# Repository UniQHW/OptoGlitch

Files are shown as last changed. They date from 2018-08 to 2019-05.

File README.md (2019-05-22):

# OptoGlitch

GIF

Turning an Arduino, a LED and a Photo Resistor into an physical glitch art filter!

## Showcase

Original:
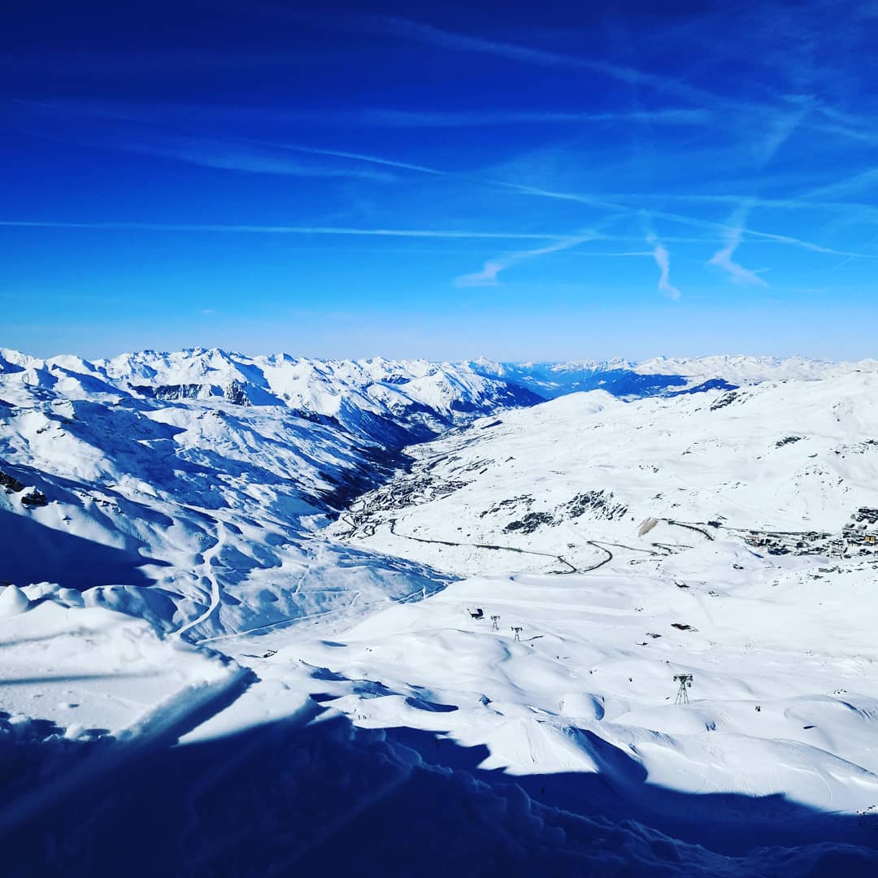
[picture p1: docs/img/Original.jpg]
Original


Parsed:
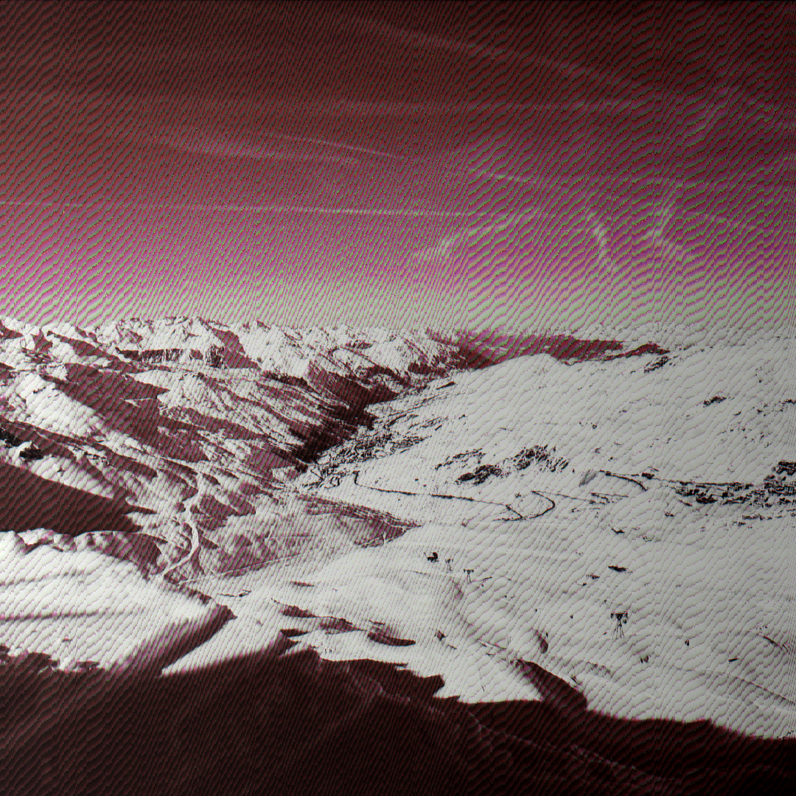
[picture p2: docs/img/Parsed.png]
Parsed


## Prelude

It is absolutely no secret that I have an unhealthy obsession with the aesthetics manifested by analogous errors. Despite the fact that the VHS Cassette was already being replaced by its digital competitor, the DVD, by the time I was born, I was still fortunate enough to become one of the last witnesses of the legendary video format. The time stamps, the "play" button, the washed out colors and static noise will always invoke a warm feeling of nostalgia for me. And it is due to this induced nostalgia, that my desire in glitch art strives after the analogous error.

Since the introduction of digital media formats, we have become spoiled in media quality. As an result, we now treat analogous error as an visual aesthetic, and ironically often attempt to digitally recreate it. I myself must obviously admit, that I proudly contribute to the digital recreation of analogous error, in form of glitch art. While I have yet to get my hands on a proper VHS recorder or camcorder, I have attempted to improvise by finding alternate ways of analogous data transfer that do not require access to the rather complex electronics found in a VHS recorder. And that is exactly what has lead to this project. While the results certainly vary from VHS glitches, I must admit that I am still very satisfied by the errors caused through analogous noise.

## Overview

OptoGlitch is an Arduino project that attempts to artificially induce analogous errors by passing image data through an optocoupler circuit.

### Hardware
The optocoupler consists of nothing more than a photo resistor, a LED (blue in our case) and two resistors, where one drives the LED (220 Ohm) and the other acts as a voltage reference for the photo resistor input (330 Ohm).

The schematic looks as it follows:

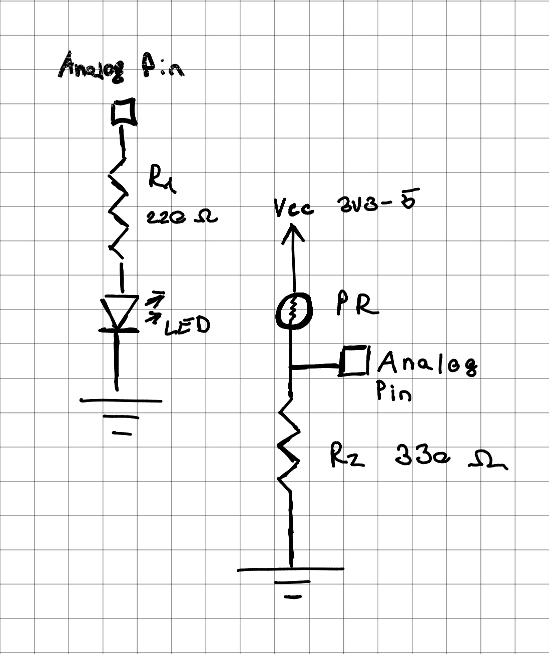
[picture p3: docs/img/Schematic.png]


Since the choice of analog pins is interchangeable, the schematic generalizes them. In the case of this project, the currently utilized pins can be found in the [pin header](src/Pins.h).

Since I was so satisfied with the results delivered by this project, I have also decided to 3D print an enclosure for the circuitry. The internal wiring estimates the following sketch:

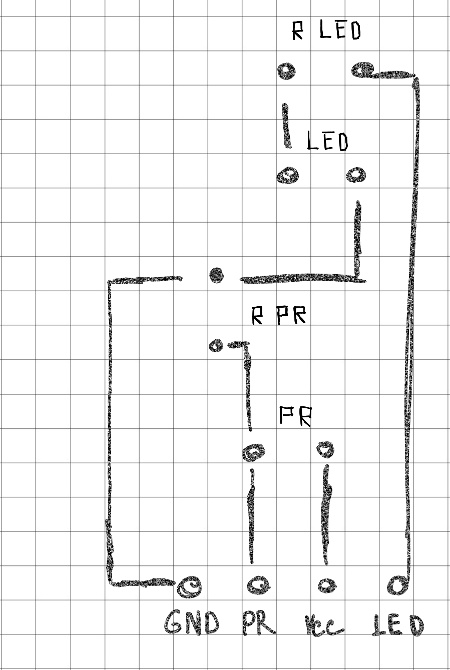
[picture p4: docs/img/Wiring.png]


In its enclosure, the device turned out to look and function quite neatly:

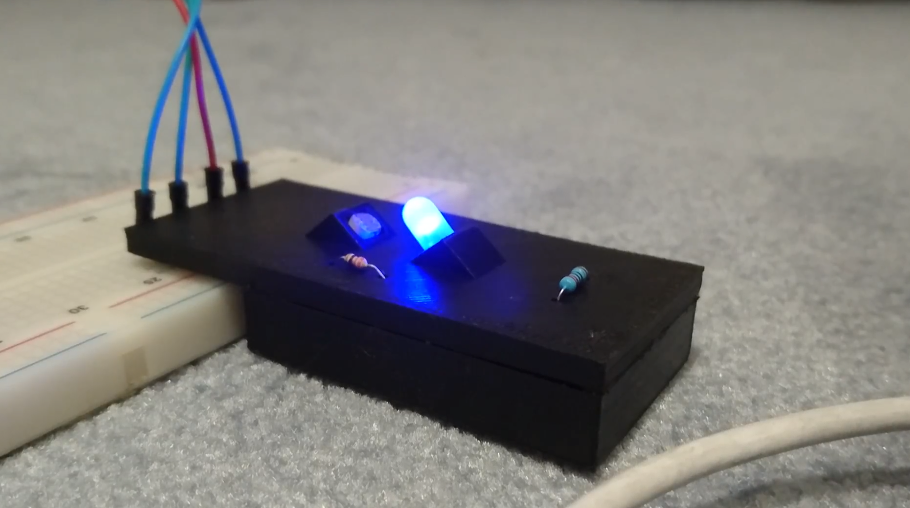
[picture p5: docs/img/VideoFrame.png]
3D Printed Enclosure


Notice that the photo resistor and LED are raised at a 45 degree angle. This grants easier access for manual interference and allows the photo resistor to capture environmental noise.

The STL files for the 3D printed enclosure can be found here:

- [top](stl/Top.stl)
- [bottom](stl/Bottom.stl)

### Software

The transmission of data is achieved by setting the LED to the brightness of the pixel value (ex. (255, 0, 120) would first set the LED to 255 brightness then 0 brightness and then 120 brightness). The photo resistor captures the brightness of the LED, and the software attempts match the photo resistor input to its original pixel value through various calibration methods. Since the process is analogous, it is prone to noise caused by external light sources. Additionally, the Arduino can only distinguish between a finite set of voltage levels. These, and many more factors result in erroneous readings, which are then responsible for the glitch aesthetics.

#### Calibration
Since the photo resistor readings are ranged in values 0 - 1023 (unlike the LEDs range of 0 - 255) and will substantially vary from the LED brightness, they must be calibrated for images not to become completely unrecognizable. The Arduino software offers a total of two calibration modes, each compensating for the value deviation in a different way.

##### Standard Deviation

With this calibration method, all 256 LED brightness levels (0 - 255) are compared to the photo resistor input prior image parsing. From the received set of mean readings (256 values in total), the Arduino then computes the standard deviation between the mean readings and the LED brightness that they should match.

Once the image parsing process begins, all photo resistor values are subtracted by- or added to the standard deviation, depending whether the photo resistor value is smaller or greater than the LED brightness.

To set the calibration mode to standard deviation, pass the following serial command while the device is idling:

```
set cmode stddev
```

##### Lookup Table

Just as with the standard deviation, the lookup table calibibration takes place before an image is parsed. The lookup table calibration loads a total of 256 photo resistor readings, one for each LED brightness, into an array.

Once the image parsing process begins, the photo resistor value is mapped to its nearest matching array entry.

**The lookup table calibration is the default calibration mode** and is vastly superior to the standard deviation when it comes to color accuracy. Its slight drawback comes from the prolonged parsing time.

To set the calibration mode to lookup table, pass the following serial command while the device is idling:

```
set cmode lookup
```

##### No calibration

If one desires to utilize photo resistor readings in their pure form, calibration can be disabled with the following serial command:

```
set cmode none
```

In most cases this will yield very light images since the photo resistor readings can range from values 0 - 1023, thus any readings that are greater than 255 will be reduced to a value of 255.

##### Other properties

The intensity of error can be further reduced through the implementation of a mean reading. A mean reading is determined by calculating the average of a set of photo resistor inputs for a specific brightness, rather than just relying on a single sample. The amount of samples to calculate the mean can be specified through the serial console via the `set samples` command. For instance, `set samples 0` will skip the calculation of a mean and simply rely on a single reading. Contrary, `set samples 100` will tell the Arduino to collect a total of 100 samples per brightness and then calculate the mean. By default, the `samples` property is set to 0.

Original:

Original

---

`set samples 0` on standard deviation:

No Args

Parse time: 00:30 Seconds

---

`set samples 50` on standard deviation:

50 Samples

Parse time: 03:26 min

---

`set samples 100` on standard deviation:

100 samples

Parse time: 06:03 min

With sample rate, color accuracy and parse time rises.

Further, we tend to reach the end of an threshold, as change in the mean reduces with more values provided.

Another property that can greatly reduce error is the `transition` property. Just like the mean sample rate, the transition property can be set through the serial console via the `set transition` command. The transition property defines the given time in ms for the LED to change its brightness. Giving the LED more time to change its brightness reduces the risk of developing artifacts from the previous pixel value. By default the transition time is set to 0, as such an error often provides desired aesthetics.

Original:

Original

---

`set transition 0` on standard deviation:

No Args

Parse time: 00:30 Seconds

---

`set transition 1`  on standard deviation:

1 ms transition

Parse time: 01:00 min

---

`set transition 5` on standard deviation:

5 ms transition

Parse time: 03:00 min

---

`set transition 10` on standard deviation:

10 ms transition

Parse time: 05:31 min

Once again, the accuracy and time rises. Obviously an LED only a fixed amount of time to fully change its brightness. As a result, it is isn't recommended to set this property to values above 10ms, as no notable improvements should be visible.

Utilizing both properties will clearly yield the best results, if those are desired:

Original:

Original

---

`set samples 100` and `set transition 5` on standard deviation:

Samples and Transition

Parse time: 08:34 min

### Usage

Since this project revolves primarily around the distortion of image files, I have written a host sided tool in python called [ParseImage.py](host/ParseImage.py), which reads an image file and parses each pixel by pixel through the OptoGlitch via serial communication.

The following python libraries are required by [ParseImage.py](host/ParseImage.py):

- [pySerial](https://pyserial.readthedocs.io/en/latest/index.html)
- [Pillow](https://pillow.readthedocs.io/en/latest/)

Usage:
```
usage: ParseImage.py [-h] [-p PORT] [-b BAUD] [-c CALIBRATION] [-dt TIMEOUT]
                     [-ht HOST_TIMEOUT] [-t TRANSITION] [-s SAMPLES]
                     [-nmax NOISE_MAX] [-nmin NOISE_MIN]
                     img

Parses images through the Arduino optocoupler

positional arguments:
  img                   Path to an image file

optional arguments:
  -h, --help            show this help message and exit
  -p PORT, --port PORT  Serial port (Default '/dev/ttyACM0')
  -b BAUD, --baud BAUD  Baud rate (Default 115200)
  -c CALIBRATION, --calibration CALIBRATION
                        Calibration mode (none, stddev, lookup)
  -dt TIMEOUT, --timeout TIMEOUT
                        Device serial communication timeout (Default 0, no
                        timeout)
  -ht HOST_TIMEOUT, --host_timeout HOST_TIMEOUT
                        Host serial communication timeout (Default 0, no
                        timeout)
  -t TRANSITION, --transition TRANSITION
                        Transition time for LED (Default 0, no transition
                        time)
  -s SAMPLES, --samples SAMPLES
                        PR input samples to determine a mean reading (Default
                        0, rely on a single sample only)
  -nmax NOISE_MAX, --noise_max NOISE_MAX
                        Maximum digitally generated noise
  -nmin NOISE_MIN, --noise_min NOISE_MIN
                        Minimum digitally generated noise
```

#### Example

In the following example we parse an image with the calibration mode set to the **standard deviation**, the transmission time set to **1 ms** and the mean sample rate set at **50 samples**:

```
python ParseImage.py -c stddev -t 1 -s 50 image.png
```

## Further reading

If you are interested as to why the OptoGlitch produces some of its unique glitch artificats, then I encourage you to take a look at [this document](https://docs.google.com/document/d/1IXgLr-epezUETSYK8bRIUSsdWn0loQHT_kls9pORURU/edit?usp=sharing), where I go as far as to inspect the device with an oscilloscope.

## License

This project is licensed by the GPLv3

```
Copyright (C) 2018 Patrick Pedersen <ctx.xda@gmail.com>

This program is free software: you can redistribute it and/or modify
it under the terms of the GNU General Public License as published by
the Free Software Foundation, either version 3 of the License, or
(at your option) any later version.

This program is distributed in the hope that it will be useful,
but WITHOUT ANY WARRANTY; without even the implied warranty of
MERCHANTABILITY or FITNESS FOR A PARTICULAR PURPOSE.  See the
GNU General Public License for more details.

You should have received a copy of the GNU General Public License
along with this program.  If not, see <https://www.gnu.org/licenses/>.
```

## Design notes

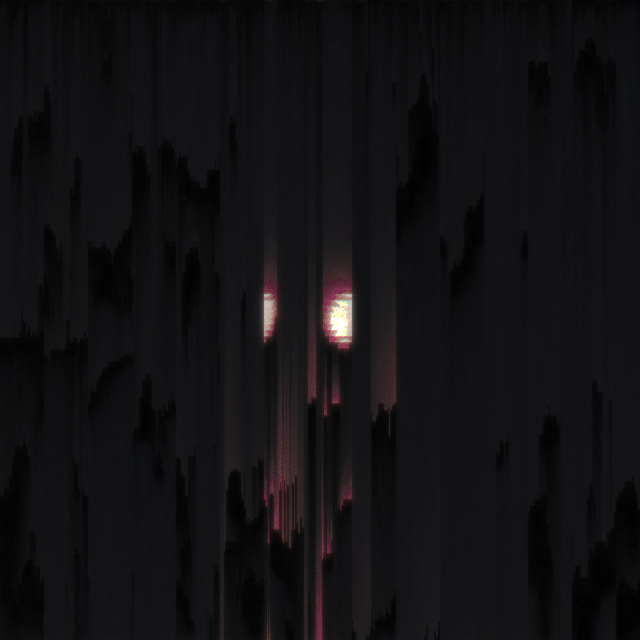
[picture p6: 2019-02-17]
host/Parsed.png

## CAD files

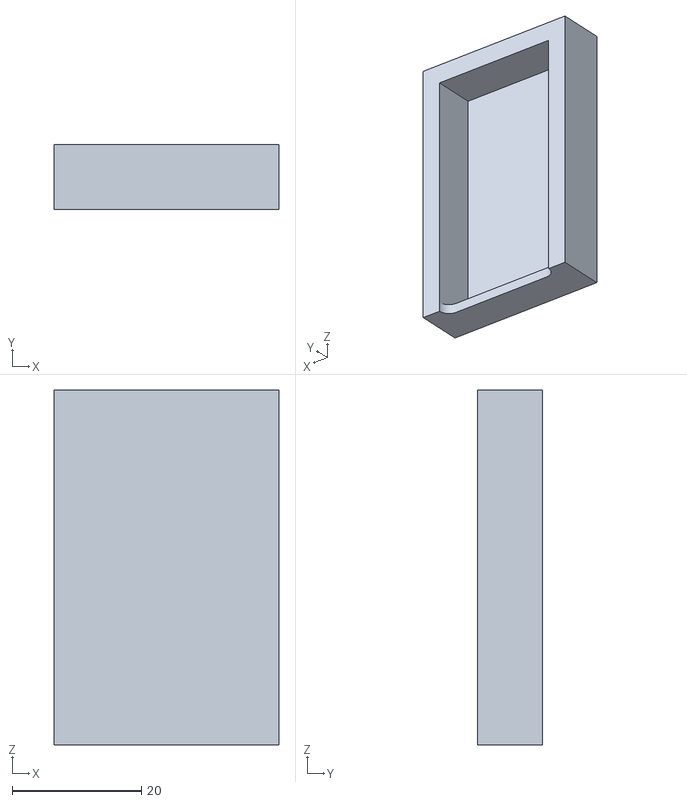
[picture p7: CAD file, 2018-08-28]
stl/Bottom.stl
34.8 x 10.0 x 55.0

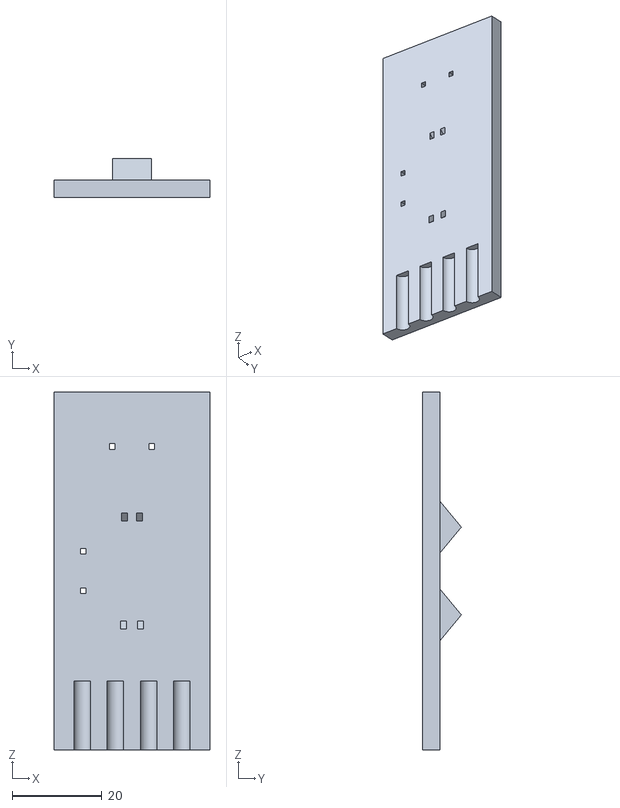
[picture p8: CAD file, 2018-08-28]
stl/Top.stl
34.8 x 8.66 x 80.0

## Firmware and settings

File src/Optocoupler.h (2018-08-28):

/*

* Copyright (C) 2018 Patrick Pedersen <ctx.xda@gmail.com>

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
 * Description:
 * Provides the main optocoupler class.

*/

#include <Arduino.h>

#pragma once

#define APPEND_SPACE(STR)             STR " "

// Set Arguments
#define SET_ARG_CALIBRATION_MODE      "cmode"                          // Set calibration mode
#define SET_ARG_TIMEOUT               "timeout"                        // Set communication timeout
#define SET_ARG_TRANSITION_TIME       "transition"                     // Set LED transition time
#define SET_ARG_MEAN_SAMPLES          "samples"                        // Set size of PR sample pool to determine a mean value
#define SET_ARG_NOISE_GENERATOR_MAX   "nmax"                           // Maximum random noise that can be generated
#define SET_ARG_NOISE_GENERATOR_MIN   "nmin"                           // Minimum random noise that must be generated
#define MIN_SET_ARG_SIZE              sizeof(SET_ARG_NOISE_GENERATOR_MAX) // Option with least characters

// Calibartion mode arguments
#define CALIBARTION_MODE_ARG_NONE     "none"   // No calibration
#define CALIBARTION_MODE_ARG_STDDEV   "stddev" // Standard deviation
#define CALIBARTION_MODE_ARG_LOOKUP   "lookup" // Lookup table

// LOOKUP TABLE SIZE
#define LOOKUP_TABLE_SIZE         1024 // Max possble analog read values

// Default properties
#define DEFAULT_TIMEOUT           0
#define DEFAULT_TRANSMISSION_TIME 0
#define DEFAULT_MEAN_SAMPLES      0
#define DEFAULT_CALIBRATION_MODE  lookup

// Typedefs
typedef unsigned long payload_size_t;

// Calibration Modes
enum CalibrationMode
{
  none,    // NO CALIBRATION (Colors will be very inacurate)
  stddev,  // Standard deviation
  lookup   // Mean Lookup table
};

// Optocoupler
// -----------------------------------------
// A pseudo-random noise generator that adds
// or subtracts random values from provided
// data
// -----------------------------------------
class NoiseGenerator
{
 public:
   NoiseGenerator();

   bool is_enabled();
   void set_max_noise(uint8_t max);
   void set_min_noise(uint8_t min);

   int generate();
   void disable();

 private:
   int16_t max_noise;
   int16_t min_noise;
   bool enabled;
};

// Optocoupler
// -----------------------------------------------------
// A hardware abstraction interface to communicate
// and controll the analogous and errornous optocoupler.
// -----------------------------------------------------
class Optocoupler
{
 public:
   Optocoupler(uint8_t tx, uint8_t rx);
   void reset_properties();         // Resets object properties to their default values
   bool apply_set_cmd(String cmd);  // Sets parameters via a provded serial "set" command
   bool parse(payload_size_t payload_size); // Accepts and parses a serial data payload through the optocoupler

 private:
   uint8_t tx; // LED
   uint8_t rx; // Photo Resistor

   // Input Accuracy
   unsigned int timeout;
   unsigned int transmission_time;
   unsigned int mean_samples;

   int mean_reading();

   // Calibration
   CalibrationMode calibration_mode;
   unsigned int calibration_transmission_time       = 10;
   unsigned int calibration_mean_samples            = 255;

   int calibration_mean_reading();
   int calibration_std_deviation();

 public: // DEBUG
   uint16_t *calibration_lookup_table();

   // Digital Randomization
   NoiseGenerator noise_generator;
};

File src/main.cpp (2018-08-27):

/*

* Copyright (C) 2018 Patrick Pedersen <ctx.xda@gmail.com>

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
 * Description:
 * Main code for the the analogous and errornous arduino optocoupler.
 * Initialization and serial commands are handled here.

*/

#include <Arduino.h>
#include "Pins.h"
#include "Optocoupler.h"

#define  ERROR_BLINK_INTERVAL_MS  250

// success
// ------------------------------------------
// Informs of success via the serial console
// ------------------------------------------
void
success()
{
    Serial.write(1);
}

// error
// ------------------------------------------
// Informs of an error via the serial console
// and builting LED blinking
// ------------------------------------------
void
error(String msg)
{
  Serial.println(msg);

  // Blink builtin LED 3 times
  for (int8_t i = 5; i >= 0; i--) {
    digitalWrite(LED_BUILTIN, (i&0x1)); // Shhh.... we AND the LSB of i for 1 (see bitmasking)
    delay(ERROR_BLINK_INTERVAL_MS);
  }
}

/* -- MAIN -- */

Optocoupler *oc;

void
setup()
{
  Serial.begin(115200);

  pinMode(LED_BUILTIN, OUTPUT);
  pinMode(LED_TX, OUTPUT);
  pinMode(PHOTO_RESISTOR, INPUT);

  oc = new Optocoupler(LED_TX, PHOTO_RESISTOR);
}

void
loop()
{
  // Await serial commands
  if (Serial.available() > 0)
  {
    String input = Serial.readString();

    // Set command received
    if (input.length() >= 3 && input.substring(0, 3) == "set")
    {
      if (oc->apply_set_cmd(input)) {
        success();
      } else {
        error("Invalid set property given!");
      }
    }

    // Reset command received
    else if (input.length() >= 5 && input.substring(0, 5) == "reset")
    {
      oc->reset_properties();
      success();
    }

    // Parse command received
    else if (input.length() >= 5 && input.substring(0, 5) == "parse")
    {
      if (input.length() > 6)
      {
        payload_size_t payload_size = input.substring(6).toInt();

        if (payload_size)
        {
          if (oc->parse(payload_size)) {
            success();
          } else {
            error("Lost connecton to host!");
          }
        }
        else
        {
          error("Invalid payload size given!");
        }
      }
      else
      {
        error("No payload size given!");
      }
    }

    // Invalid Command received
    else
    {
      error("No such command: " + input);
    }
  }
}

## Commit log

2018-08-27 Optocoupler: Make calibration part of the optocoupler class
2018-08-27 Optocoupler: Parse: Evaluate sign of deviation
    With the recent hardware migration to my 3d printed case, the LED
    is now driven by a resistor to prevent a short. In addition to that,
    the PR is significantly further away from the LED than during the
    breadboard setup. As a result, the PR reads significantly lower values
    than before. A quick log has proven that the received signals result,
    for the most part, in a lower value that than the brightness provided to
    the LED. Interestingly, there's also a point where the LED input is lower to
    the value received by the PR. As a result, we no longer only subtract the deviation,
    but compare the LED brightness and PR input first, and then conclude whether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
    [Optocoupler.cpp]
2018-08-27 Optocoupler: Add option to disable calibration
2018-08-27 Optocoupler: Added digital noise generator
    [Optocoupler.cpp, Optocoupler.h, ParseImage.py]
2018-08-27 Optocoupler: Parse: Test calibration mode to stddev, not std_dev
2018-08-27 Host: ParseImage.py: Do not display calibration message if calibration is disabled
2018-08-27 Host: ParseImage: Reset all properties before parsing
    [ParseImage.py]
2018-08-27 Host: ParseImage: Pass tty as a parameter to reset()
    [ParseImage.py]
2018-08-27 Optocoupler: Set: Fix calibration setting
    [Optocoupler.cpp, Optocoupler.h, ParseImage.py]
2018-08-27 Host: ParseImage: Wait for respond after reset
    [ParseImage.py]
2018-08-27 Optocoupler: NoiseGenerator: Seed before generating ranom numbers
    [Optocoupler.cpp]
2018-08-28 Optocoupler: Implement lookup table calibration
2018-08-28 Optocoupler: Calibration: Set lookup as default calibration mode
2018-08-28 README: Shrink schematic and wiring size
2018-08-28 Added stl files
    [Bottom.stl, Top.stl]
2019-02-17 README: Fixed typo + added new showcase
    [ParseImage.py]
2019-03-08 README: Added reasoning for calibration
